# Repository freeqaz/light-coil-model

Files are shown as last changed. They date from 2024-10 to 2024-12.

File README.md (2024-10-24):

## Light Coil 3d Model

### Setup

Install Miniforge
```
curl -L -o miniforge.sh "https://github.com/conda-forge/miniforge/releases/latest/download/Miniforge3-$(uname)-$(uname -m).sh"
```

Create and activate conda environment
```
source $HOME/miniforge/bin/activate
conda create -y --name build123d python==3.11.9
```

Install deps
```
conda install -c conda-forge -c cadquery ocp

pip install "https://github.com/CadQuery/ocp-build-system/releases/download/7.7.2.0/cadquery_ocp-7.7.2-cp311-cp311-macosx_11_0_arm64.whl"

python3 -m pip install git+https://github.com/gumyr/bd_warehouse
```

Install VS Code extension called "OCP Cad Viewer"

I can't remember exactly how I setup the environment, it was just painful. The VS Code extension did something too and it seemed to work.

### Running

In the VS Code terminal I've been running:
```
$HOME/miniforge/envs/build123d/bin/python ./light_coil.py
```

That pulls up the CAD viewer with the model for me.

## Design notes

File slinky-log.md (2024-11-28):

# Good slinkies

1. 2024-11-18_13-50-31_coil__40c_0.34h_0.82mm_7w_22h_2.3x.json

Commit: fac3b5e2e434651b40fcae588224a1737fae0597
This one feels pretty good. Doesn't have any handles on it, but it's solid enough to flow with. Prints well with 0.8mm nozzle in Atomix UV Green PETG.

2. 2024-11-18_22-58-33_coil__38c_0.34h_0.82mm_8w_22h_2.5x.3mf

Definitely a big boi. The handle snapped on the top when printing with translucent blue PETG from Bambu. Going to try out
2024-11-19_12-39-19_coil__38c_0.34h_0.82mm_8w_19h_2.5x.3mf
and see if it's better. It has a shorter height.

Yeah the Translucent Blue PETG is a quite brittle. Chris broke it while just using it as a normal slinky. 

Printed with ironing in concentric mode worked. Will need to iterate with Thicker Bridges and determine if that's 
actually helpful or not. It requires an increase in layer height, for sure.

Also testing 2024-11-19_12-40-42_coil__5c_0.34h_0.82mm_8w_19h_2.7x.3mf to see if layer separation is better.

3. 2024-11-21_20-44-13_coil__38c_0.34h_0.82mm_6.12w_24h_2.75x.3mf

Trying to replicate the slinky from Subtronics that was printed with 0.6mm nozzle. This one is the same dimensions, though
slightlyyy wider which I think should improve the slop. Hopefully it comes out well!

Results: Solid but maybe a little too rigid. Going to round it down by a bit and try again.

Also a bit too long. Decreasing coil radius to 81mm for Nova.

4. 2024-11-22_15-04-54_coil__36c_0.34h_0.82mm_5.739999999999999w_24h_2.5x.3mf

Champion. So good!

5. Polycarbonate -- clear from Bambu Labs

It printed well at 2.3x. It looks like it used the same config I have for PETG which is wild that it worked so well on the first try. 

Going to print 2024-11-24_13-50-52_coil__35c_0.34h_0.82mm_5.739999999999999w_24h_2.5x.3mf now

6. PC one I think and something else

Going to test with "Print infill first" and "Only one wall on top surface: not applied" to see how that influences the print.

I'm hoping it will reduce stringing because it seems like that happens when the infill prints. Could maybe mitigate with
an "even" number of walls versus odd right now (for 5.4mm width)

Preset name: 0.40mm Standard @BBL X1C 0.8 nozzle - Copy7

Print infill first is NOT the setting. Holy cow the stringing is apocalyptic!

7. Two clear ones printed with 2.3x and 2.5x

2.3x is definitely harder to pull apart. Unclear if it looks better or not. Doesn't really seem worth it over 2.5x.

For PETG-CF it seems like 2.5x isn't enough because the one I printed in white with ... some brand ... was very hard
to separate.

Going to try printing a test with `2024-11-26_19-59-56_coil__4c_0.34h_0.82mm_5.739999999999999w_24h_2.75x.3mf` and see
if it prints well at 2.75x in a pink one by ["TINMORRY" from Amazon](https://www.amazon.com/gp/product/B0DDGNP17M).

Okay, wow... so it did come apart but the lines look like trash for the first few layers. It feels like pretty
significant underextrusion. Going to try again with a smaller gap size and see.

Bar tests:
Thick bridges is bad for this. Just makes it look really janky.

Going to try decreasing width to 0.6mm and see (0.8mm nozzle).

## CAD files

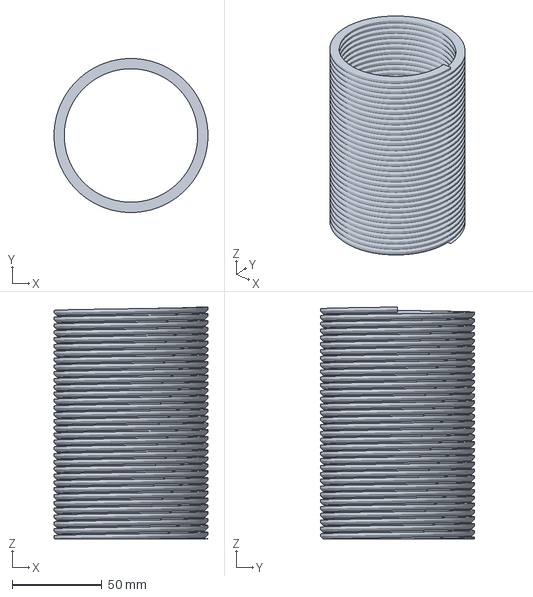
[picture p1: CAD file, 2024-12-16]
published-models/small-0.4mm-34c.3mf
85.7 x 85.7 x 129.2 mm

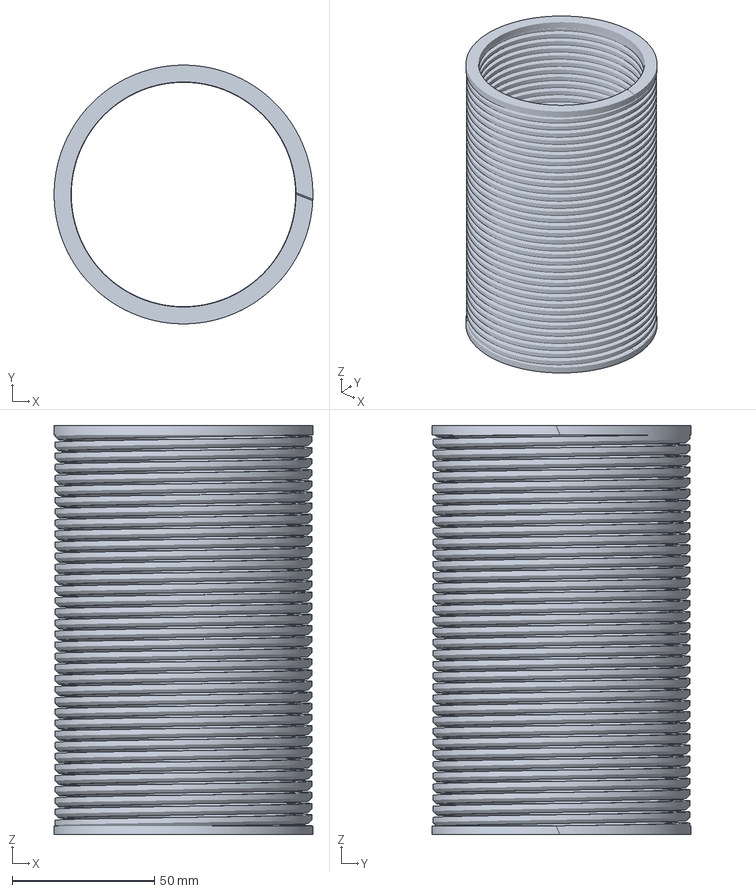
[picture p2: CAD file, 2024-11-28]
published-models/36c_0.82mm_5.74w_24h_2point5x.3mf
91.0 x 91.0 x 143.8 mm

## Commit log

2024-10-24 swap to library for threads
2024-10-25 Add LED cone assembly
2024-11-07 Attempt to make prints easier to separate
2024-11-22 Replicate slinky from subtronics that was with 0.6mm nozzle
2024-11-28 Add latest iteration and a published 0.8mm nozzle model
    [36c_0.82mm_5.74w_24h_2point5x.3mf]
2024-12-16 Add a 0.4mm compatible model
    [small-0.4mm-34c.3mf]
